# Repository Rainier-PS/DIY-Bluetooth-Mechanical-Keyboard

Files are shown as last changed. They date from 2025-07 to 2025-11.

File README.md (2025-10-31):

# DIY Bluetooth Mechanical Keyboard

## 1. Description

The DIY Bluetooth Mechanical Keyboard is a custom-designed 3D printed wireless keyboard with an ergonomic 6 degree tilt, a slide potentiometer for analog input, USB Type-C connectivity, and hot-swappable MX-style switches. It includes a detachable wrist rest for comfort and features embedded passive NFC tags that can be used for mobile automations or other creative integrations.  

This keyboard was made to be easily built and remixed by others. The entire design uses mostly through-hole components. Only the diodes are surface-mount, which makes it much easier to assemble without needing any special tools.

---

## 2. Why I Made This Project

I designed this keyboard for myself with daily use in mind. I wanted something compact, reliable, and comfortable to use, especially during long sessions. Most wireless keyboards don't come with embedded passive NFC tags and some still even use micro USB for charging and wired mode. This one uses USB Type-C and Bluetooth, and can also be recharged easily.

The project also gave me a chance to learn about PCB layout, 3D CAD, component sourcing, and firmware setup. I wanted to build something I could be proud of and share with others who might want to build their own.

---

## Project Gallery

---

### 3D CAD Model  
cad_model

---

### PCB Design  
pcb_layout

---

### Wiring Diagram  
wiring_diagram

---

## Bill of Materials (BOM)

| No. | Category | Item | Qty | Est. Price (USD) | Description / Notes | Link |
|-----|---|---|---|---|---|---|
| 1 | Switch & Keycap | Gateron Milky Yellow Pro | 64 pcs | 12 | Smooth linear switches with factory lube | https://www.tokopedia.com/mechkeyboardsid/gateron-g-pro-yellow-switch-linear-plate-mount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 |
| 2 | Switch & Keycap | Kailh Hot Swap Sockets | 64 pcs | 5 | For hot-swappable MX-style switches | https://www.tokopedia.com/mechkeyboardsid/kailh-hot-swap-mechanical-keyboard-pcb-socket-black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 |
| 3 | Switch & Keycap | Keycap Set | 1 set  | 20 | Full keycap set, likely PBT | https://tk.tokopedia.com/ZSBVvFJGR/ |
| 4 | Switch & Keycap | Stabilizer Set | 1 set  | 10 | For spacebar, shift, enter, etc. | https://tk.tokopedia.com/ZSBpk1MKy/ |
| 5 | Electronics | Nice!Nano V2 (Clone) | 2 pcs  | 8 | Wireless controller with ZMK support | https://tk.tokopedia.com/ZSSLQ4ugF/ |
| 6 | Electronics | MCP23017 E/SP | 1 pc | 7 | GPIO Expander | https://www.tokopedia.com/iibuuffeellaaa/ic-chips-mcp23017-e-sp-dip-28-mcp23017-16-bit-i-o-expander-with-i2c-interface-ic-original-integrated-circuits-17312333555570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 |
| 7 | Electronics | LiPo Battery | 1 pc | 4 | Powers the keyboard wirelessly | https://tk.tokopedia.com/ZSBpAFa1Y/ |
| 8 | Electronics | JST Connector | 1 pc | 1 | Connects battery to PCB | https://tk.tokopedia.com/ZSBpAYkm3/ |
| 9 | Electronics | 1N4148 Diodes (SOD-123) | 100 pcs | 1 | For keyboard matrix | https://www.tokopedia.com/i2c-parts/in4148-1n4148-1n4148ws-sod123-switching-diode-sod-123-dioda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 |
| 10  | Electronics | 10K Slide Potentiometers | 10 pcs | 1 | For analog controls like volume | https://www.tokopedia.com/innovtronic/b10k-mono-slide-potentio-75mm-high-quality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 |
| 11  | Fasteners | M2.5 6mm Heat Inserts  | 6 pcs  | 1 | For securing threaded parts in plastic | https://tk.tokopedia.com/ZSBqKcnqk/ |
| 12  | Fasteners | M2.5 8mm Screws | 6 pcs  | 1 | For case and PCB mounting | https://www.tokopedia.com/archive-lapaktukang/baut-komputer-laptop-m2-5x4-m2-5x5-m2-5x6-m2-5x8-m2-5x10-m2-5x8-mm-hitam-d5-7f72b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 |
| 13  | Damping & Isolation | EVA Foam 3mm | 1 pc | 2 | For internal case dampening | https://www.tokopedia.com/tentakey/eva-foam-untuk-case-plate-foam-modding-mechanical-keyboard-25x30-2mm-26c32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 |
| 14  | Damping & Isolation | Non-slip Feet | 1 set  | 1 | Anti-slip support | https://tk.tokopedia.com/ZSBqsCjBn/ |
| 15  | Assembly | Solder Wire | 1 pc | 2 | For assembling components | https://tk.tokopedia.com/ZSAR33vra/ |
| 16  | Assembly | Solder Paste | 1 pc | 3 | For assembling components (SMD) | https://tk.tokopedia.com/ZSAR3KArf/ |
| 17  | Assembly | Flux | 1 pc | 1 | Improves solder quality, especially for SMD components  | |
| 18  | PCB & Electronics | Custom PCB | 5 pcs  | 16 | Custom-designed keyboard circuit board | — |
| 19  | Case Components | Case | 1 pc | 3 | One-piece keyboard case (price is reserved for shipping, tentative) | — |
| 20  | Case Components | Wristrest | 1 pc | 3 | Wristrest (price is reserved for shipping, tentative) | — |
| 21  | Feature Add-on | Passive NFC Tags | 1 pack | 4 | Embedded for automation (e.g. launch phone shortcut) | https://tk.tokopedia.com/ZSBVtqGWa/ |

Total: $106 USD

> Prices are rounded up to the next whole dollar.

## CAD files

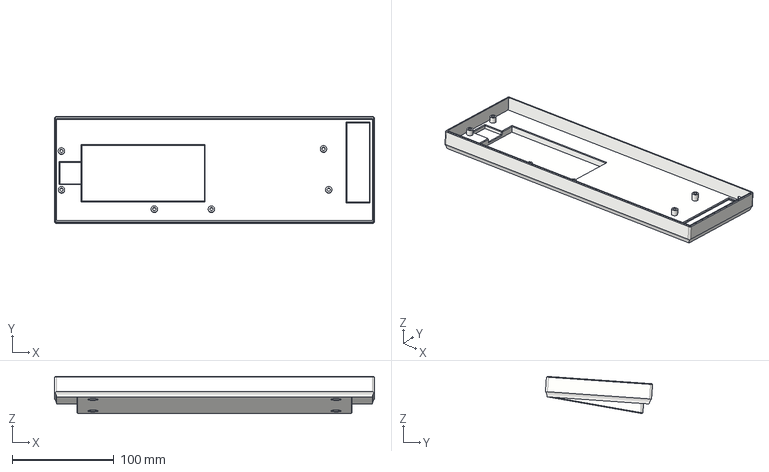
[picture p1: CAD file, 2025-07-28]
cad/Case.step
314.0 x 105.2 x 36.5 mm

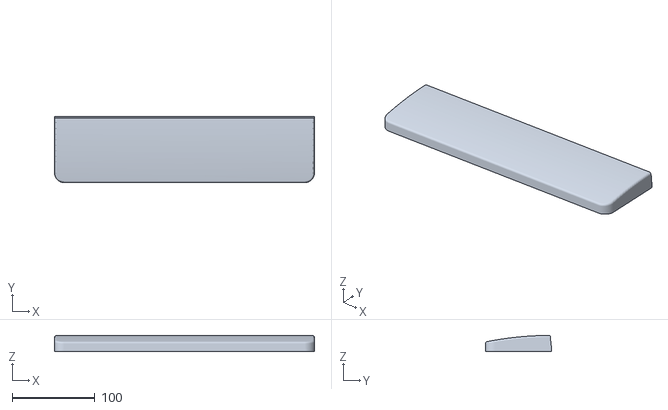
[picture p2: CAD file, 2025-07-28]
production/Wristrest.stl
314.0 x 80.0 x 19.7

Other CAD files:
cad/Wristrest.step
production/Case.stl

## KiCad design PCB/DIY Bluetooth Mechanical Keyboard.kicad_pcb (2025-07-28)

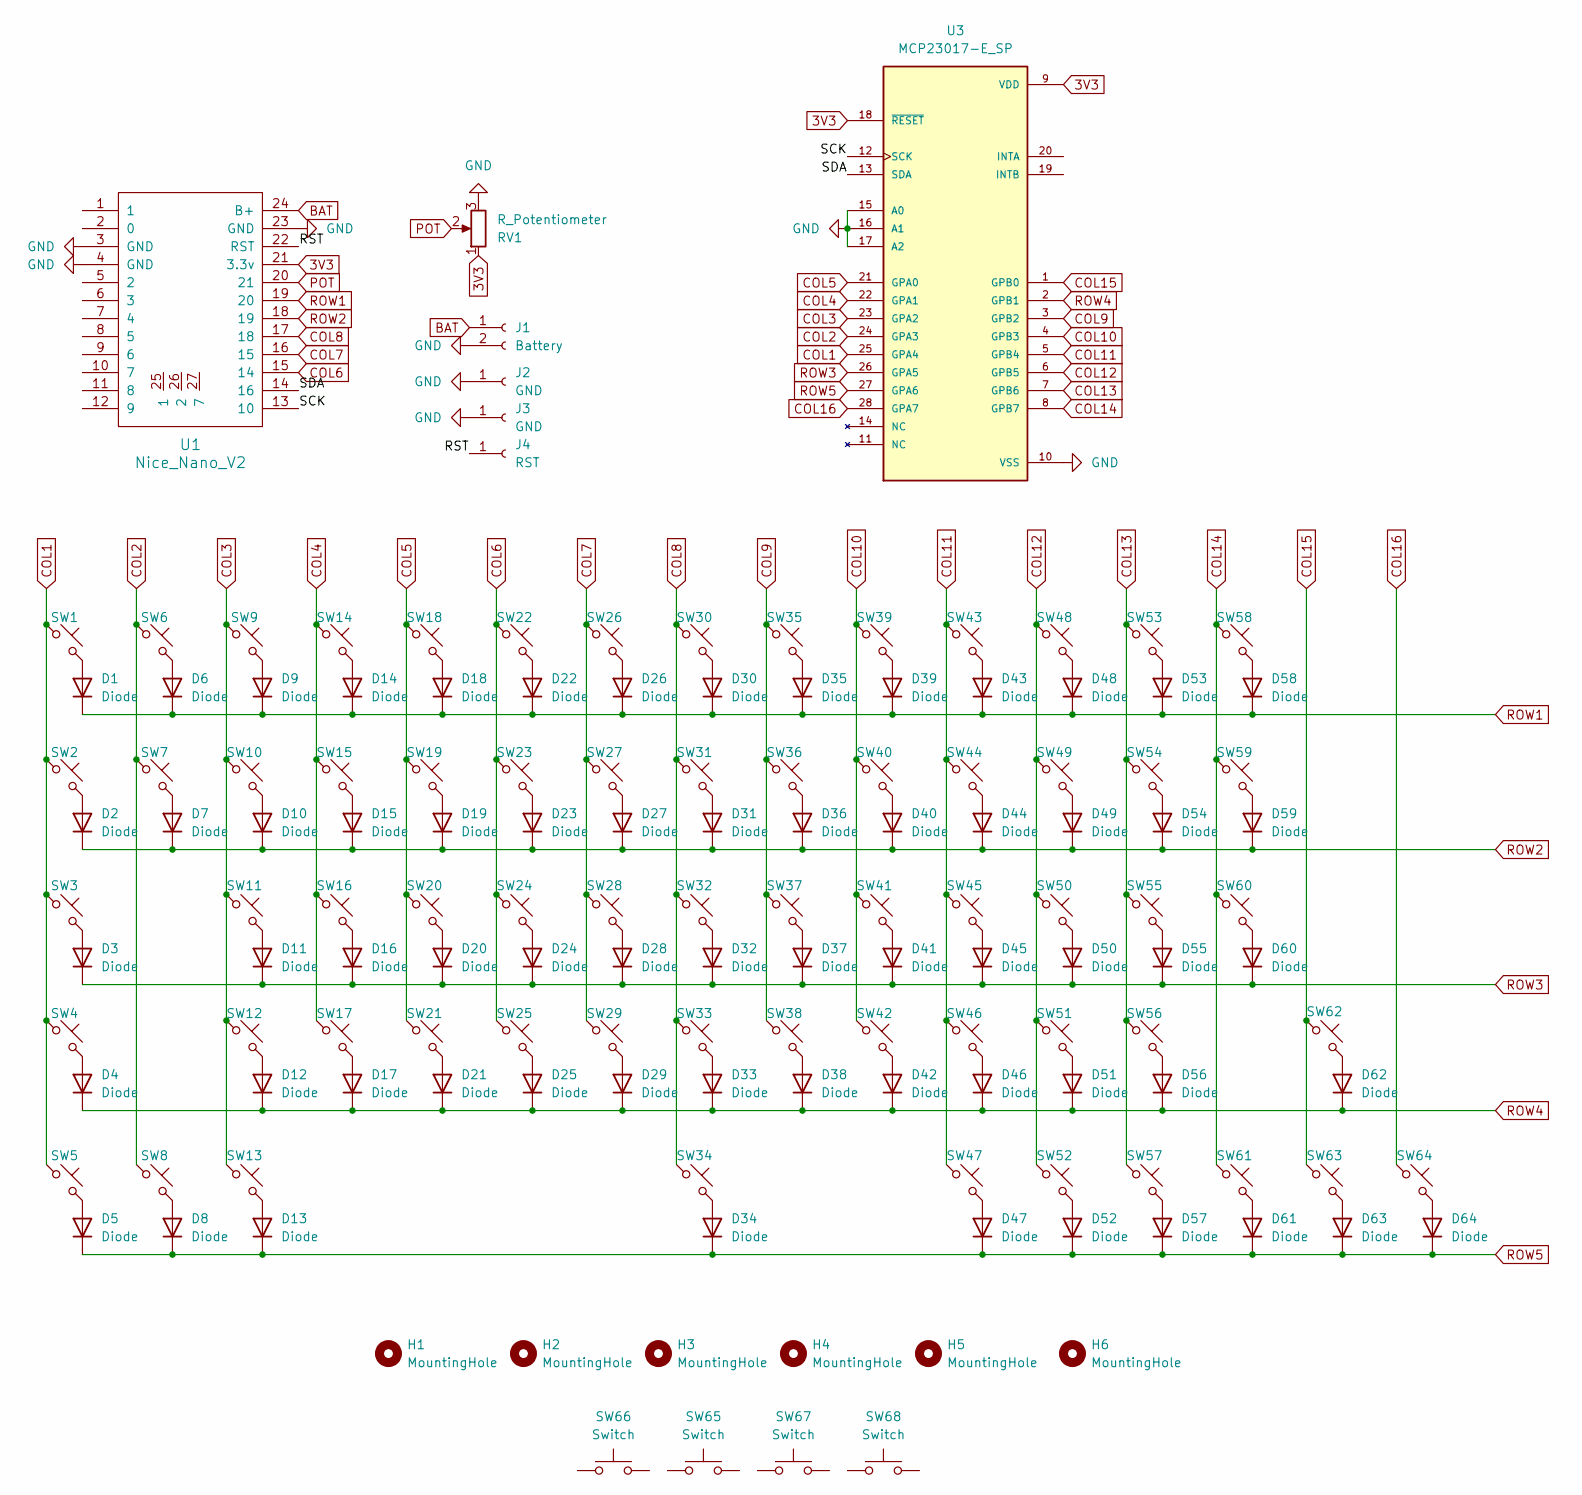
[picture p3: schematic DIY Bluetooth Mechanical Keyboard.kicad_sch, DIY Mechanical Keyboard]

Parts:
D1, D2, D3, D4, D5, D6, D7, D8, D9, D10, D11, D12, D13, D14, D15, D16, D17, D18, D19, D20, D21, D22, D23, D24, D25, D26, D27, D28, D29, D30, D31, D32, D33, D34, D35, D36, D37, D38, D39, D40, D41, D42, D43, D44, D45, D46, D47, D48, D49, D50, D51, D52, D53, D54, D55, D56, D57, D58, D59, D60, D61, D62, D63, D64: Diode; D_0805_2012Metric_Pad1.15x1.40mm_HandSolder
H1, H2, H3, H4, H5, H6: MountingHole; MountingHole_2.7mm_M2.5
J1: Battery; JST_PH_B2B-PH-K_1x02_P2.00mm_Vertical
J2: GND; TestPoint_THTPad_D2.0mm_Drill1.0mm
J3: GND; TestPoint_Pad_1.5x1.5mm
J4: RST; TestPoint_Pad_1.5x1.5mm
RV1: R_Potentiometer; Sliding_Pot
SW1, SW6, SW7, SW8, SW9, SW10, SW11, SW12, SW13, SW14, SW15, SW16, SW17, SW18, SW19, SW20, SW21, SW22, SW23, SW24, SW25, SW26, SW27, SW28, SW29, SW30, SW31, SW32, SW33, SW35, SW36, SW37, SW38, SW39, SW40, SW41, SW42, SW43, SW44, SW45, SW46, SW48, SW49, SW50, SW51, SW53, SW54, SW55, SW57, SW61, SW62, SW63, SW64: SW_Push_45deg; Hotswap_MX_Plated_1.00u
SW2, SW59: SW_Push_45deg; Hotswap_MX_Plated_1.50u
SW3, SW56: SW_Push_45deg; Hotswap_MX_Plated_1.75u
SW4, SW60: SW_Push_45deg; Hotswap_MX_Plated_2.25u
SW5, SW47, SW52: SW_Push_45deg; Hotswap_MX_Plated_1.25u
SW34: SW_Push_45deg; Hotswap_MX_Plated_6.25u
SW58: SW_Push_45deg; Hotswap_MX_Plated_2.00u
SW65, SW66, SW67: Switch; Stabilizer_MX_2.00u
SW68: Switch; Stabilizer_MX_6.25u
U1: Nice_Nano_V2
U3: MCP23017-E_SP; DIP787W45P254L3556H508Q28; PARTREV D

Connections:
3V3: RV1.1, U1.21 (3.3v), U3.9 (VDD), U3.18 (~RESET)
/RST: J4.1, U1.22 (RST); also elsewhere on the board
/SCK: U1.13 (10), U3.12 (SCK)
/SDA: U1.14 (16), U3.13 (SDA)
BAT: J1.1, U1.24 (B+); also elsewhere on the board
COL1: SW1.1, SW2.1, SW3.1, SW4.1, SW5.1, U3.25 (GPA4)
COL2: SW6.1, SW7.1, SW8.1, U3.24 (GPA3)
COL3: SW9.1, SW10.1, SW11.1, SW12.1, SW13.1, U3.23 (GPA2)
COL4: SW14.1, SW15.1, SW16.1, SW17.1, U3.22 (GPA1)
COL5: SW18.1, SW19.1, SW20.1, SW21.1, U3.21 (GPA0)
COL6: SW22.1, SW23.1, SW24.1, SW25.1, U1.15 (14)
COL7: SW26.1, SW27.1, SW28.1, SW29.1, U1.16 (15)
COL8: SW30.1, SW31.1, SW32.1, SW33.1, SW34.1, U1.17 (18)
COL9: SW35.1, SW36.1, SW37.1, SW38.1, U3.3 (GPB2)
COL10: SW39.1, SW40.1, SW41.1, SW42.1, U3.4 (GPB3)
COL11: SW43.1, SW44.1, SW45.1, SW46.1, SW47.1, U3.5 (GPB4)
COL12: SW48.1, SW49.1, SW50.1, SW51.1, SW52.1, U3.6 (GPB5)
COL13: SW53.1, SW54.1, SW55.1, SW56.1, SW57.1, U3.7 (GPB6)
COL14: SW58.1, SW59.1, SW60.1, SW61.1, U3.8 (GPB7)
COL15: SW62.1, SW63.1, U3.1 (GPB0)
COL16: SW64.1, U3.28 (GPA7)
GND: J1.2, J2.1, J3.1, RV1.3, U1.3 (GND), U1.4 (GND), U1.23 (GND), U3.10 (VSS), U3.15 (A0), U3.16 (A1), U3.17 (A2); also elsewhere on the board
unnamed: D1.2 (A), SW1.2
unnamed: D2.2 (A), SW2.2
unnamed: D3.2 (A), SW3.2
unnamed: D4.2 (A), SW4.2
unnamed: D5.2 (A), SW5.2
unnamed: D6.2 (A), SW6.2
unnamed: D7.2 (A), SW7.2
unnamed: D8.2 (A), SW8.2
unnamed: D9.2 (A), SW9.2
unnamed: D10.2 (A), SW10.2
unnamed: D11.2 (A), SW11.2
unnamed: D12.2 (A), SW12.2
unnamed: D13.2 (A), SW13.2
unnamed: D14.2 (A), SW14.2
unnamed: D15.2 (A), SW15.2
unnamed: D16.2 (A), SW16.2
unnamed: D17.2 (A), SW17.2
unnamed: D18.2 (A), SW18.2
unnamed: D19.2 (A), SW19.2
unnamed: D20.2 (A), SW20.2
unnamed: D21.2 (A), SW21.2
unnamed: D22.2 (A), SW22.2
unnamed: D23.2 (A), SW23.2
unnamed: D24.2 (A), SW24.2
unnamed: D25.2 (A), SW25.2
unnamed: D26.2 (A), SW26.2
unnamed: D27.2 (A), SW27.2
unnamed: D28.2 (A), SW28.2
unnamed: D29.2 (A), SW29.2
unnamed: D30.2 (A), SW30.2
unnamed: D31.2 (A), SW31.2
unnamed: D32.2 (A), SW32.2
unnamed: D33.2 (A), SW33.2
unnamed: D34.2 (A), SW34.2
unnamed: D35.2 (A), SW35.2
unnamed: D36.2 (A), SW36.2
unnamed: D37.2 (A), SW37.2
unnamed: D38.2 (A), SW38.2
unnamed: D39.2 (A), SW39.2
unnamed: D40.2 (A), SW40.2
unnamed: D41.2 (A), SW41.2
unnamed: D42.2 (A), SW42.2
unnamed: D43.2 (A), SW43.2
unnamed: D44.2 (A), SW44.2
unnamed: D45.2 (A), SW45.2
unnamed: D46.2 (A), SW46.2
unnamed: D47.2 (A), SW47.2
unnamed: D48.2 (A), SW48.2
unnamed: D49.2 (A), SW49.2
unnamed: D50.2 (A), SW50.2
unnamed: D51.2 (A), SW51.2
unnamed: D52.2 (A), SW52.2
unnamed: D53.2 (A), SW53.2
unnamed: D54.2 (A), SW54.2
unnamed: D55.2 (A), SW55.2
unnamed: D56.2 (A), SW56.2
unnamed: D57.2 (A), SW57.2
unnamed: D58.2 (A), SW58.2
unnamed: D59.2 (A), SW59.2
unnamed: D60.2 (A), SW60.2
unnamed: D61.2 (A), SW61.2
unnamed: D62.2 (A), SW62.2
unnamed: D63.2 (A), SW63.2
unnamed: D64.2 (A), SW64.2
POT: RV1.2, U1.20 (21)
ROW1: D1.1 (K), D6.1 (K), D9.1 (K), D14.1 (K), D18.1 (K), D22.1 (K), D26.1 (K), D30.1 (K), D35.1 (K), D39.1 (K), D43.1 (K), D48.1 (K), D53.1 (K), D58.1 (K), U1.19 (20)
ROW2: D2.1 (K), D7.1 (K), D10.1 (K), D15.1 (K), D19.1 (K), D23.1 (K), D27.1 (K), D31.1 (K), D36.1 (K), D40.1 (K), D44.1 (K), D49.1 (K), D54.1 (K), D59.1 (K), U1.18 (19)
ROW3: D3.1 (K), D11.1 (K), D16.1 (K), D20.1 (K), D24.1 (K), D28.1 (K), D32.1 (K), D37.1 (K), D41.1 (K), D45.1 (K), D50.1 (K), D55.1 (K), D60.1 (K), U3.26 (GPA5)
ROW4: D4.1 (K), D12.1 (K), D17.1 (K), D21.1 (K), D25.1 (K), D29.1 (K), D33.1 (K), D38.1 (K), D42.1 (K), D46.1 (K), D51.1 (K), D56.1 (K), D62.1 (K), U3.2 (GPB1)
ROW5: D5.1 (K), D8.1 (K), D13.1 (K), D34.1 (K), D47.1 (K), D52.1 (K), D57.1 (K), D61.1 (K), D63.1 (K), D64.1 (K), U3.27 (GPA6)

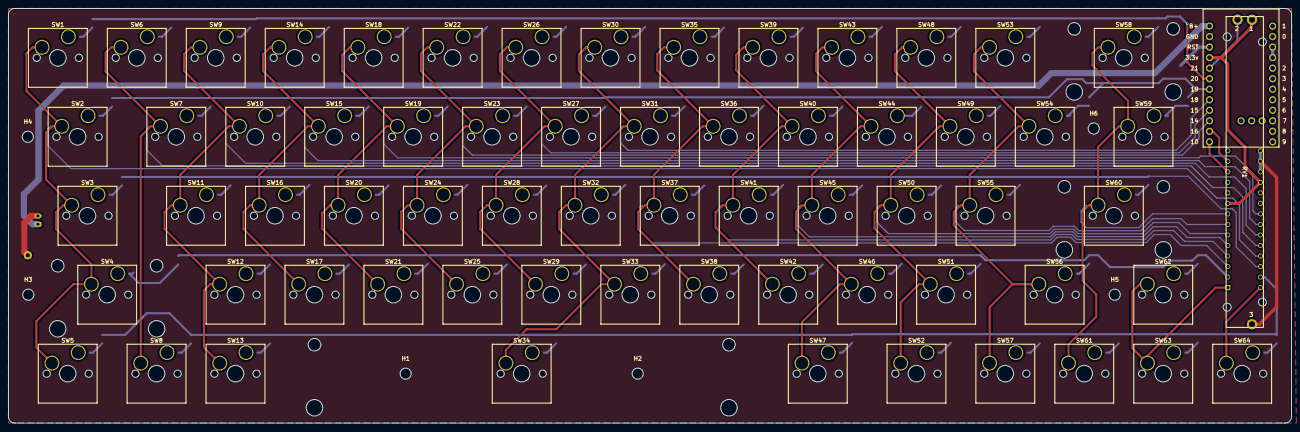
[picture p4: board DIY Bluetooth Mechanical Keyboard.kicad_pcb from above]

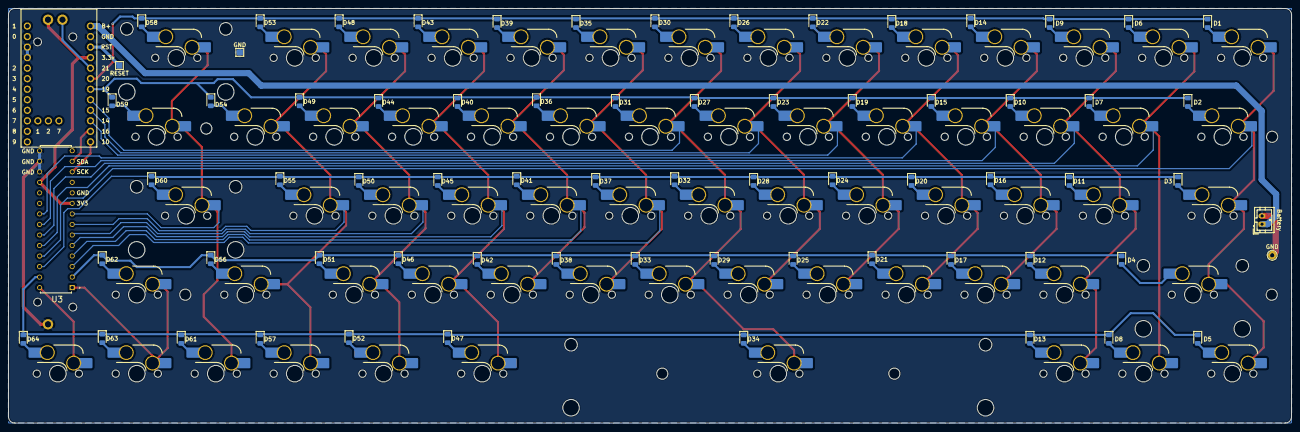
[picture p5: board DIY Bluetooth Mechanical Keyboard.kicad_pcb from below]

Board: 2 copper layers, 309.6 x 100.0 mm, 145 parts (70 on the bottom side), 92 nets.

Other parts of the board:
Battery: Battery; JST_PH_B2B-PH-K_1x02_P2.00mm_Vertical
GND: GND; TestPoint_THTPad_D2.0mm_Drill1.0mm
GND#2: GND; TestPoint_Pad_1.5x1.5mm
RESET: RST; TestPoint_Pad_1.5x1.5mm

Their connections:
/RST: RESET.1; also elsewhere on the board
BAT: Battery.1; also elsewhere on the board
GND: Battery.2, GND.1, GND#2.1; also elsewhere on the board

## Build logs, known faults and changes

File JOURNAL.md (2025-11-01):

# DIY Bluetooth Mechanical Keyboard
---
Author: Rainier Pearson Saputra

Created at: 2025-07-11

**Total Time Spent: 30 hours**
---

# July 11 – Planning, BOM, and Schematics

I started this project by planning what I actually wanted out of the keyboard. I knew it had to be wireless, compact, and clean-looking, but I also wanted a few uncommon features like a slide potentiometer for volume and passive NFC tags for automations. I decided early on that this would be a 60% layout without a function row, and everything had to be rechargeable over USB Type-C.

After deciding on the features, I began selecting components and building the initial BOM. I browsed Tokopedia to find all the parts I needed. I went with Gateron Milky Yellows, a Nice!Nano V2 for wireless support, hot-swap sockets, and a JST connector for the battery. I also chose EVA foam for sound dampening and rubber feet for anti-slip.

Once I was done with part selection and BOM creation, I moved into KiCad and created the schematic. I designed a 5 by 16 keyboard matrix and wired everything up to the Nice!Nano. With the schematic complete and everything properly labeled, I was ready to move on to PCB layout the next day.

* **Image:** Schematics

* **Time Spent: 4.5 hours**

---

# July 12 – PCB Design and Routing

Today was mostly spent inside KiCad. I started by assigning all the footprints to their symbols and laying out the matrix on the PCB. I spent a long time positioning the switches and tracks to make sure everything fits nicely.

After that I routed the power lines and connected everything to the Nice!Nano. I also added a JST connector footprint, screw mounting holes, and some basic silkscreen labels to help with assembly.

* **Image:** PCB Design

* **Time Spent: 9 hours**

---

# July 13 – Case Design (CAD)

With the STEP export of the PCB ready, I opened Fusion 360 and started designing the case. The concept was to make it minimalist and clean, with no visible screws on the outside and an inclined base that is ergonomic and comfortable for long typing sessions. 

On the inside, I designed clearance around the USB port, slide potentiometer, and created the standoffs for screw mount.

* **Image:** Case Design

* **Time Spent: 6.5 hours**

---

# July 14 – Switch and Detail Modeling

Today was mostly focused on adding in switch models and checking component fittings. I did this because I fear that some components won't fit nicely on the final build.

I also designed small pockets inside the walls of the case for passive NFC tags, and finalized how the detachable wrist rest would mount.

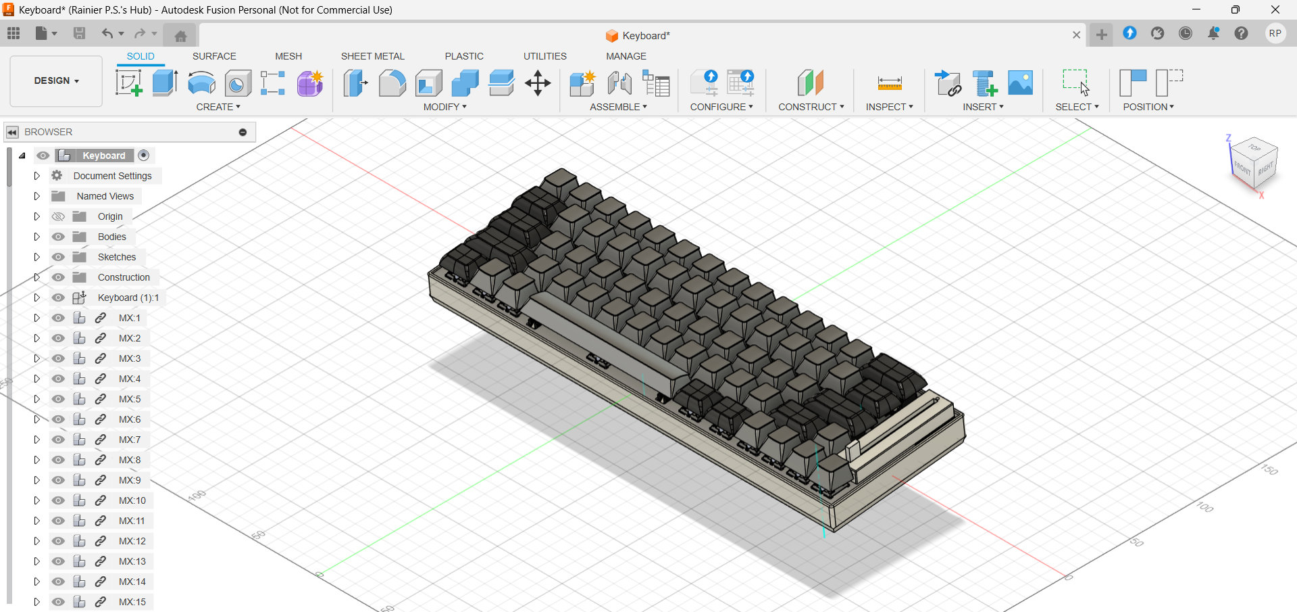
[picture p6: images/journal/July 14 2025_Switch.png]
Component Fitting
* **Image:** 

* **Time Spent: 5 hours**

---

# July 15 – Final Polish and Repo Upload

I spent the day finishing everything off. In Fusion 360 I added the wrist rest, then exported the case, wristrest, and the full assembly as STEP. 

Once all the files were ready, I organized everything into a GitHub repo. I uploaded the BOM, CAD models, KiCad PCB files, and my journal file. Now it's all ready to be submitted.

* **Image:** Final Polish

* **Time Spent: 5 hours**

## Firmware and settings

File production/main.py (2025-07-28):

from kmk.kmk_keyboard import KMKKeyboard
from kmk.modules.layers import Layers
from kmk.scanners.keypad import MatrixScanner
from kmk.scanners.analog import AnalogScanner
from kmk.keys import KC

import board
import busio
from adafruit_mcp230xx.mcp23017 import MCP23017

keyboard = KMKKeyboard()
keyboard.modules.append(Layers())

# --- Setup I2C and MCP23017 ---
i2c = busio.I2C(scl=board.D10, sda=board.D16)  # GPIO10=SCL, GPIO16=SDA
mcp = MCP23017(i2c, address=0x20)  # A0, A1, A2 grounded -> 0x20

# --- MCP23017 Pins ---
mcp_rows = [
    mcp.get_pin(5),   # GPA5 = ROW3
    mcp.get_pin(1 + 8),  # GPB1 = ROW4
    mcp.get_pin(6),   # GPA6 = ROW5
]

mcp_cols = [
    mcp.get_pin(4),   # GPA4 = COL1
    mcp.get_pin(3),   # GPA3 = COL2
    mcp.get_pin(2),   # GPA2 = COL3
    mcp.get_pin(1),   # GPA1 = COL4
    mcp.get_pin(0),   # GPA0 = COL5
    mcp.get_pin(2 + 8),   # GPB2 = COL9
    mcp.get_pin(3 + 8),   # GPB3 = COL10
    mcp.get_pin(4 + 8),   # GPB4 = COL11
    mcp.get_pin(5 + 8),   # GPB5 = COL12
    mcp.get_pin(6 + 8),   # GPB6 = COL13
    mcp.get_pin(7 + 8),   # GPB7 = COL14
    mcp.get_pin(0 + 8),   # GPB0 = COL15
    mcp.get_pin(7),   # GPA7 = COL16
]

# Set direction for MCP pins
for pin in mcp_rows:
    pin.switch_to_input(pull=None)
for pin in mcp_cols:
    pin.switch_to_output(value=True)

# --- Nice!Nano Direct Pins ---
direct_rows = [
    board.D20,  # GPIO20 = ROW1
    board.D19,  # GPIO19 = ROW2
]

direct_cols = [
    board.D14,  # GPIO14 = COL6
    board.D15,  # GPIO15 = COL7
    board.D18,  # GPIO18 = COL8
]

# --- Combine into a single matrix ---
# Order: COL1–COL16, ROW1–ROW5

keyboard.matrix = MatrixScanner(
    cols=mcp_cols + direct_cols,  # COL1–COL16 (MCP) + COL6–COL8 (Direct)
    rows=direct_rows + mcp_rows,  # ROW1–ROW5 (2 Direct + 3 MCP)
    columns_to_anodes=True
)

# --- KEYMAP (Example Only!) ---
keyboard.keymap = [
    [  # row x column layout: 5 rows × 16 columns
        KC.ESC, KC._1, KC._2, KC._3, KC._4, KC._5, KC._6, KC._7, KC._8, KC._9, KC._0, KC.MINS, KC.EQL, KC.BSPC, KC.NO, KC.NO,
        KC.TAB, KC.Q, KC.W, KC.E, KC.R, KC.T, KC.Y, KC.U, KC.I, KC.O, KC.P, KC.LBRC, KC.RBRC, KC.BSLS, KC.NO, KC.NO,
        KC.CAPS, KC.A, KC.S, KC.D, KC.F, KC.G, KC.H, KC.J, KC.K, KC.L, KC.SCLN, KC.QUOT, KC.NO, KC.ENT, KC.NO, KC.NO,
        KC.LSFT, KC.Z, KC.X, KC.C, KC.V, KC.B, KC.N, KC.M, KC.COMM, KC.DOT, KC.SLSH, KC.NO, KC.NO, KC.NO, KC.NO, KC.RSFT,
        KC.LCTL, KC.LGUI, KC.LALT, KC.SPC, KC.SPC, KC.RALT, KC.RGUI, KC.APP, KC.LEFT, KC.DOWN, KC.UP, KC.RGHT, KC.NO, KC.NO, KC.NO, KC.RCTL,
    ]
]

if __name__ == '__main__':
    keyboard.go()
